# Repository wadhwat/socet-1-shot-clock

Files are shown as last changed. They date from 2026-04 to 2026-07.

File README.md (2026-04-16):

# socet-1-shot-clock

Authors 
* Tejas Wadhwa
* Jean-Milan Albarede
* Mehmet Mercan
* Hemant Garg
* Ian Kozloski

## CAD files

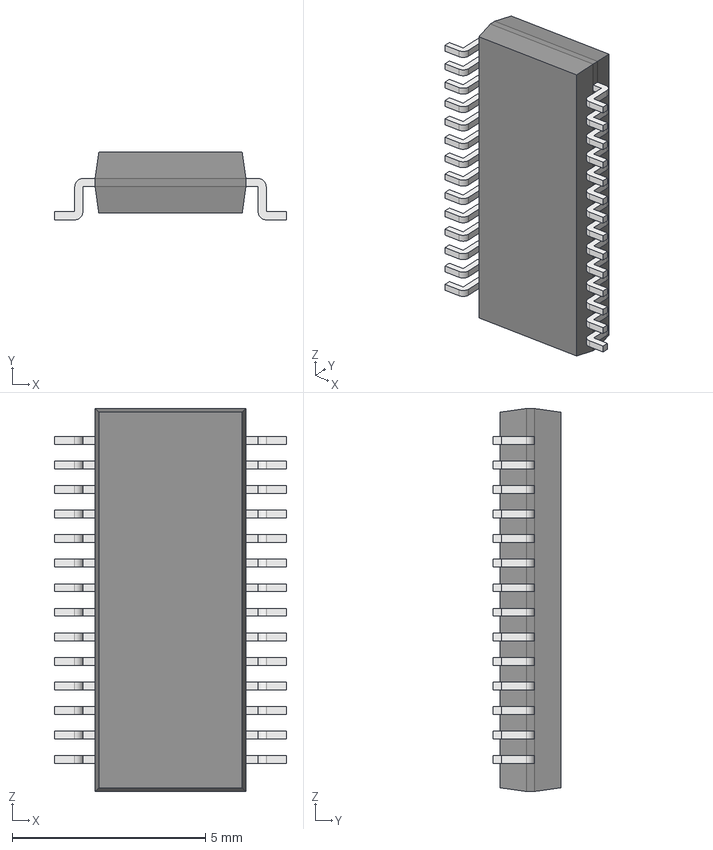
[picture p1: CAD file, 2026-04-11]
KiCad_Files/ShotClockPCB/ProjFootprintLib/HT16K33A-28SSOP (1)/HT16K33A-28SSOP.step
6.00 x 1.75 x 9.90 mm
Body001 (Mirror #1) x 14
XY-plane x 12
X-axis x 12

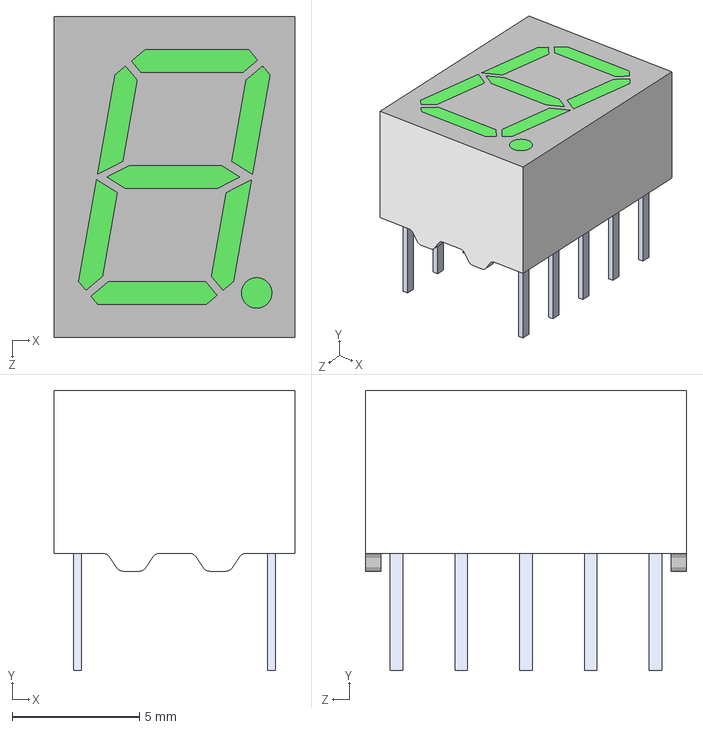
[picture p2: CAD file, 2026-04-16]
KiCad_Files/TDSG3150/TDSG3150.step
9.45 x 11.0 x 12.6 mm

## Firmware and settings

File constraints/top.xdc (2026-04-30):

## =========================================================
## top.xdc
## Target board: Digilent Arty S7-25
## HDL top module: sv/src/top.sv
##
## Board pin reference:
##   constraints/Arty-S7-25-Master.xdc
##
## PCB source:
##   KiCad_Files/ShotClockPCB/17pinPCB/17pinPCB.kicad_pcb
##
## Top module ports:
##   clk
##   rst_in
##   btn_start_stop_raw
##   btn_possession_raw
##   btn_score_up_raw
##   btn_score_down_raw
##   btn_shot_reset_raw
##   period_leds[3:0]
##   possession_leds[1:0]
##   buzzer_drive
##   display_select[3:0]
##   display_segments[7:0]
##   colon_out
##   gc_colon_out
##   sc_colon_out
##   scr_colon_out
##
## Confirmed PCB-to-Arty mappings:
##   PCB net      Arty label  FPGA pin  HDL port
##   Colon        IO1         N13       colon_out
##   SEG_A        IO33        V15       display_segments[0]
##   SEG_B        IO7         V17       display_segments[1]
##   SEG_C        IO3         R14       display_segments[2]
##   SEG_D        IO6         R17       display_segments[3]
##   SEG_E        IO0         L13       display_segments[4]
##   SEG_F        IO5         R16       display_segments[5]
##   SEG_G        IO2         L16       display_segments[6]
##   SEG_DP       IO4         T14       display_segments[7]
##   SEL_A0       IO29        T13       display_select[0]
##   SEL_A1       IO30        T12       display_select[1]
##   SEL_A2       IO31        V13       display_select[2]
##   SEL_A3       IO32        U12       display_select[3]
##   Buzzer       IO28        R11       buzzer_drive
##   LED_POS_HOME IO26        U11       possession_leds[0]
##   LED_POS_AWAY IO27        T11       possession_leds[1]
##   SW1          sw[1]       H18       btn_start_stop_raw
##   BTN0         btn[0]      G15       btn_possession_raw
##   BTN1         btn[1]      K16       btn_score_up_raw
##   BTN2         btn[2]      J16       btn_score_down_raw
##   BTN3         btn[3]      H13       btn_shot_reset_raw
##   SW0          sw[0]       H14       rst_in
##   LED_P1       A7          A14       period_leds[0]
##   LED_P2       A8          D16       period_leds[1]
##   LED_P3       A9          D17       period_leds[2]
##   LED_P4       A10         D14       period_leds[3]
##
## Assumptions:
##   - Display segment bit order is display_segments[7:0] = {dp,g,f,e,d,c,b,a}.
##   - Button mapping follows top.sv comments:
##       pb[0]=start/stop, pb[1]=possession, pb[2]=score up,
##       pb[3]=score down, pb[4]=shot reset, pb[5]=reset.
##   - Unconfirmed signals are left commented out intentionally so Vivado does
##     not silently use stale PMOD-header assumptions.
## =========================================================

## 100 MHz onboard clock
set_property -dict { PACKAGE_PIN R2 IOSTANDARD SSTL135 } [get_ports { clk }];
create_clock -add -name sys_clk_pin -period 10.000 -waveform {0.000 5.000} [get_ports { clk }];

## ---------------------------------------------------------
## Confirmed display segment nets
## HDL: display_segments[7:0] = {dp,g,f,e,d,c,b,a}
## ---------------------------------------------------------
set_property -dict { PACKAGE_PIN V15 IOSTANDARD LVCMOS33 } [get_ports { display_segments[0] }]; # SEG_A -> IO33 / ck_io33
set_property -dict { PACKAGE_PIN V17 IOSTANDARD LVCMOS33 } [get_ports { display_segments[1] }]; # SEG_B -> IO7  / ck_io7
set_property -dict { PACKAGE_PIN R14 IOSTANDARD LVCMOS33 } [get_ports { display_segments[2] }]; # SEG_C -> IO3  / ck_io3
set_property -dict { PACKAGE_PIN R17 IOSTANDARD LVCMOS33 } [get_ports { display_segments[3] }]; # SEG_D -> IO6  / ck_io6
set_property -dict { PACKAGE_PIN L13 IOSTANDARD LVCMOS33 } [get_ports { display_segments[4] }]; # SEG_E -> IO0  / ck_io0
set_property -dict { PACKAGE_PIN R16 IOSTANDARD LVCMOS33 } [get_ports { display_segments[5] }]; # SEG_F -> IO5  / ck_io5
set_property -dict { PACKAGE_PIN L16 IOSTANDARD LVCMOS33 } [get_ports { display_segments[6] }]; # SEG_G -> IO2  / ck_io2
set_property -dict { PACKAGE_PIN T14 IOSTANDARD LVCMOS33 } [get_ports { display_segments[7] }]; # SEG_DP -> IO4 / ck_io4

## ---------------------------------------------------------
## Confirmed LEDs
## ---------------------------------------------------------
set_property -dict { PACKAGE_PIN U11 IOSTANDARD LVCMOS33 } [get_ports { possession_leds[0] }]; # LED_POS_HOME -> IO26 / ck_io26
set_property -dict { PACKAGE_PIN T11 IOSTANDARD LVCMOS33 } [get_ports { possession_leds[1] }]; # LED_POS_AWAY -> IO27 / ck_io27
set_property -dict { PACKAGE_PIN A14 IOSTANDARD LVCMOS33 } [get_ports { period_leds[0] }];     # LED_P1       -> A7   / ck_a7
set_property -dict { PACKAGE_PIN D16 IOSTANDARD LVCMOS33 } [get_ports { period_leds[1] }];     # LED_P2       -> A8   / ck_a8
set_property -dict { PACKAGE_PIN D17 IOSTANDARD LVCMOS33 } [get_ports { period_leds[2] }];     # LED_P3       -> A9   / ck_a9
set_property -dict { PACKAGE_PIN D14 IOSTANDARD LVCMOS33 } [get_ports { period_leds[3] }];     # LED_P4       -> A10  / ck_a10
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

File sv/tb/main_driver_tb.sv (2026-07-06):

`timescale 1ns/1ps

module main_driver_tb;

	logic clk;
	logic tick_2640Hz;
	logic n_rst;

	logic [3:0] period_led;
	logic [1:0] pos_led;

	logic [7:0] gc_ss1;
	logic [7:0] gc_ss2;
	logic [7:0] gc_ss3;
	logic [7:0] gc_ss4;

	logic [7:0] scr_ss1;
	logic [7:0] scr_ss2;
	logic [7:0] scr_ss3;
	logic [7:0] scr_ss4;

	logic scr_colon;

	logic [7:0] sc_ss1;
	logic [7:0] sc_ss2;
	logic [7:0] sc_ss3;
	logic [7:0] sc_ss4;

	logic sc_colon;
	logic buzzer_in;

	logic [7:0] main_segments_pin_out;
	logic [3:0] decoder_pin;
	logic gc_colon;
	logic sc_colon_out;
	logic scr_colon_out;
	logic [3:0] period_led_out;
	logic [1:0] pos_led_out;
	logic buzzer_out;

	int err_count;

	main_driver dut (
		.clk(clk),
		.tick_2640Hz(tick_2640Hz),
		.n_rst(n_rst),
		.period_led(period_led),
		.pos_led(pos_led),
		.gc_ss1(gc_ss1),
		.gc_ss2(gc_ss2),
		.gc_ss3(gc_ss3),
		.gc_ss4(gc_ss4),
		.scr_ss1(scr_ss1),
		.scr_ss2(scr_ss2),
		.scr_ss3(scr_ss3),
		.scr_ss4(scr_ss4),
		.scr_colon(scr_colon),
		.sc_ss1(sc_ss1),
		.sc_ss2(sc_ss2),
		.sc_ss3(sc_ss3),
		.sc_ss4(sc_ss4),
		.sc_colon(sc_colon),
		.buzzer_in(buzzer_in),
		.main_segments_pin_out(main_segments_pin_out),
		.decoder_pin(decoder_pin),
		.gc_colon(gc_colon),
		.sc_colon_out(sc_colon_out),
		.scr_colon_out(scr_colon_out),
		.period_led_out(period_led_out),
		.pos_led_out(pos_led_out),
		.buzzer_out(buzzer_out)
	);

	always #5 clk = ~clk;

	task automatic check_bits(
		input string what,
		input logic [31:0] got,
		input logic [31:0] exp
	);
		if (got !== exp) begin
			err_count++;
			$error("FAIL %s: got=%0h expected=%0h @ %0t", what, got, exp, $time);
		end
	endtask

	task automatic pulse_tick;
		begin
			@(negedge clk);
			tick_2640Hz = 1'b1;
			@(posedge clk);
			#1;
			@(negedge clk);
			tick_2640Hz = 1'b0;
		end
	endtask

	task automatic check_current_mux(
		input logic [7:0] exp_seg
	);
		begin
			#1;
			check_bits($sformatf("main_segments for decoder=%0d", decoder_pin), main_segments_pin_out, exp_seg);
		end
	endtask

	initial begin
		$dumpfile("main_driver_tb.vcd");
		$dumpvars(0, main_driver_tb);

		clk = 1'b0;
		tick_2640Hz = 1'b0;
		n_rst = 1'b0;
		err_count = 0;

		period_led = 4'b1010;
		pos_led = 2'b10;

		gc_ss1 = 8'h11;
		gc_ss2 = 8'h22;
		gc_ss3 = 8'h33;
		gc_ss4 = 8'h44;

		scr_ss1 = 8'h55;
		scr_ss2 = 8'h66;
		scr_ss3 = 8'h77;
		scr_ss4 = 8'h88;

		scr_colon = 1'b1;

		sc_ss1 = 8'h99;
		sc_ss2 = 8'hAA;
		sc_ss3 = 8'hBB;
		sc_ss4 = 8'hCC;

		sc_colon = 1'b0;
		buzzer_in = 1'b1;

		// While reset is asserted, decoder is zeroed and segment output is forced off.
		#1;
		check_bits("decoder reset value", decoder_pin, 4'd0);
		check_bits("segment output during reset", main_segments_pin_out, 8'hFF);

		// Pass-through outputs should mirror their inputs.
		check_bits("gc_colon constant", gc_colon, 1'b1);
		check_bits("sc_colon passthrough", sc_colon_out, sc_colon);
		check_bits("scr_colon passthrough", scr_colon_out, scr_colon);
		check_bits("period leds passthrough", period_led_out, period_led);
		check_bits("pos leds passthrough", pos_led_out, pos_led);
		check_bits("buzzer passthrough", buzzer_out, buzzer_in);

		// Release reset and validate all mux selections.
		@(negedge clk);
		n_rst = 1'b1;
		#1;
		check_bits("decoder starts at 0 after reset release", decoder_pin, 4'd0);
		check_current_mux(gc_ss1);
		pulse_tick();

		check_bits("decoder at 1", decoder_pin, 4'd1);
		check_current_mux(gc_ss2);
		pulse_tick();

		check_bits("decoder at 2", decoder_pin, 4'd2);
		check_current_mux(gc_ss3);
		pulse_tick();

		check_bits("decoder at 3", decoder_pin, 4'd3);
		check_current_mux(gc_ss4);
		pulse_tick();

		check_bits("decoder at 4", decoder_pin, 4'd4);
		check_current_mux(scr_ss1);
		pulse_tick();

		check_bits("decoder at 5", decoder_pin, 4'd5);
		check_current_mux(scr_ss2);
		pulse_tick();

		check_bits("decoder at 6", decoder_pin, 4'd6);
		check_current_mux(scr_ss3);
		pulse_tick();

		check_bits("decoder at 7", decoder_pin, 4'd7);
		check_current_mux(scr_ss4);
		pulse_tick();

		check_bits("decoder at 8", decoder_pin, 4'd8);
		check_current_mux(sc_ss1);
		pulse_tick();

		check_bits("decoder at 9", decoder_pin, 4'd9);
		check_current_mux(sc_ss2);
		pulse_tick();

		check_bits("decoder at 10", decoder_pin, 4'd10);
		check_current_mux(sc_ss3);
		pulse_tick();

		check_bits("decoder wraps from 10 to 0", decoder_pin, 4'd0);
		check_current_mux(gc_ss1);

		// Decoder should only advance when tick_2640Hz is asserted.
		@(posedge clk);
		#1;
		check_bits("decoder holds without tick", decoder_pin, 4'd0);

		pulse_tick();
		check_bits("decoder increments to 1", decoder_pin, 4'd1);
		pulse_tick();
		check_bits("decoder increments to 2", decoder_pin, 4'd2);

		repeat (8) pulse_tick();
		check_bits("decoder reaches 10", decoder_pin, 4'd10);

		pulse_tick();
		check_bits("decoder wraps to 0", decoder_pin, 4'd0);

		// Asynchronous reset should clear decoder immediately.
		pulse_tick();
		check_bits("decoder advanced before async reset", decoder_pin, 4'd1);
		#1;
		n_rst = 1'b0;
		#1;
		check_bits("decoder async reset", decoder_pin, 4'd0);
		check_bits("segment output back to reset value", main_segments_pin_out, 8'hFF);

		if (err_count == 0)
			$display("PASS main_driver_tb");
		else
			$display("FAIL main_driver_tb errors=%0d", err_count);

		$finish;
	end

endmodule

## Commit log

2026-03-28 Added 2 folders, 1 for tick_gnenerator module and 1 for button_conditioner module
2026-03-28 created new branch Jean and made button_conditioner_tb
2026-03-28 button condoition module, not finalized
2026-03-28 button_conditioner_tb created and tested with working waveforms
2026-04-04 KiCad Files added to GitHub
    [ShotClockPCB.kicad_pcb, ShotClockPCB.kicad_sch]
2026-04-04 slight test
    [ShotClockPCB.kicad_pcb, ShotClockPCB.kicad_sch]
2026-04-04 Added KiCad Schem and KiCad footprint libraries
    [HT16K33A-28SSOP.step, ShotClockPCB.kicad_sch]
2026-04-11 feat(game_clock): tenths countdown with load and expired handling
    Implement game_clock: count down on tick_10hz when enabled, synchronous load of tenths, saturate at zero, and one-cycle expired pulse on 1→0 transition.
    On load, assert expired when enable is high and load value is zero (already expired).
    Extend game_clock_tb: reset and readback, full-period load, explicit load-0 with enable, randomized loads, mid-run load, enable gating, expiry and saturation checks.
    [game_clock_tb.sv]
2026-04-11 Added temporary I/O for top_module
    [17pinPCB.kicad_pcb, 17pinPCB.kicad_sch, TDSG3150.step]
2026-04-12 Updated testbench to verify slot_tick, disp_sel, and correct slot behavior
2026-04-12 Added constraints & changed n_rst to rst, to align with reset button in constraints.
2026-04-12 Added constraints & changed n_rst to rst, to align with reset button in constraints. Properly staged.
2026-04-13 Fixed program to output 1kHz and 10Hz
2026-04-14 Initial PCB schematic sans LEDs and buzzer
    [17pinPCB.kicad_sch]
2026-04-14 Added LED to schematic
    [17pinPCB.kicad_sch]
2026-04-16 finalized PCB design
    [17pinPCB-B_Cu.gbr, 17pinPCB-B_Mask.gbr, 17pinPCB-B_Silkscreen.gbr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]
2026-04-16 Added a 12Hz output to the tick_generator
2026-04-23 Completed main_driver, not tb, added new 2640 Hz output for tick_generator
2026-04-23 Created score_driver, added buzzer output in main driver
2026-04-23 Merged main driver, buzzer driver, and score_driver from Jean branch
2026-04-25 Ignore generated KiCad files
2026-04-25 Implement scoreboard control FSM
    Wire the control FSM into the top level for game-clock enable/load, period advancement, possession toggling, shot-clock reset outputs, and buzzer triggering. Rename the countdown module/testbench to clock, reset the game clock to the configured full period, and clean up seven-segment width assignments.
    [clock_tb.sv]
2026-04-25 Show score overflow with decimal point
    Allow score_tracker to count beyond the two-digit display limit and have score_driver clamp overflowing scores to 99 with the decimal point lit on the overflowing team's ones digit. Also finish the c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
2026-04-25 Update clock driver display formatting
2026-04-25 created possession testbench, aligned possession with top and main driver
2026-04-30 Add main-board hardware bring-up tests
    - Remap top-level controls to Arty switches/buttons for hardware debugging
    - Fix main display scan loop to cover all 12 digit-select states
    - Update top-level testbench scan expectation for the full display cycle
    - Rework buzzer smoke test for the main-board buzzer pin with 2.4 kHz drive
    - Add buzzer activity LED indicator on LED_P1
    - Add standalone possession LED test with manual toggle and auto-cycle modes
    [possession_led_test.xdc, top.xdc]
